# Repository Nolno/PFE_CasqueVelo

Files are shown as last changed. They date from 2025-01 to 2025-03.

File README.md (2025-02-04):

# PFE_CasqueVelo

Super projet où font qu'on arrive à faire un casque de vélo connecté qui permet de détecter la perte d'attention d'enfants atteint du syndrome de Smith Magenis.  

On les prévient ensuite avec une alerte sonore ou visuelle.

# Membres
Sahah 🌞  

Camille 😎  

Antoine 🗿  

Nolan 🫠

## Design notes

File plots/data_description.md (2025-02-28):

# Acquisitions avec le MPU6050
Le MPU6050 est la centrale inertielle que nous avons utilisée en premier, c'était celle présente sur le prototype.
Elle est composée d'un accéléromètre et d'un gyroscope, qui permettent de mesurer l'accélération et la vitesse angulaire du capteur.

### Plot 1
Le premier plot représente les angles d'Euler en fonction du temps sur 300 secondes, récupérés sur la carte master. On observe la dérive du yaw (lacet) au cours du temps, qui est due à l'accumulation d'erreurs du gyroscope. 

La calibration du gyroscope se faisait sur 10 boucles.

### Plot 2
Le deuxième plot présente la même chose mais avec une calibration plus longue (100 boucles). On n'observe que peu d'impact sur la dérive du yaw.

### Plot 3
Le troisième plot représente la même chose sur le slave, avec une calibration de 100 boucles. La dérive est légèrement 
plus faible, ce qui s'explique probablement par le fait que les deux capteurs ne sont pas exactement les mêmes.

### Plot 4
Le troisième plot représente la même chose sur le master, avec une calibration de 100 boucles, pendant 1h30. La dérive continue de s'accumuler pour atteindre 20° en 1h30.

# Acquisitions avec le IMU ICM20948
Le ICM20948 est la centrale inertielle que nous avons utilisée en deuxième, c'est celle que nous avons choisi pour remplacer le MPU6050.
Elle est composée d'un accéléromètre, d'un gyroscope et d'un magnétomètre, qui permettent de mesurer l'accélération, la vitesse angulaire et l'orientation du capteur.
L'intérêt du magnétomètre est de pouvoir mesurer l'orientation du capteur par rapport au champ magnétique terrestre, ce qui permet de compenser la dérive du yaw.

### Plot 5
Acquisition des angles d'Euler sur 370 secondes avec le ICM20948. Le yaw ne dérive pas, ce qui est cohérent avec l'utilisation du magnétomètre. Il est cependant plus bruité qu'avec le MPU6050.
Au bout de 300 secondes, on incline légèrement le capteur.

### Plot 6
Acquisition en conditions réelles sur le vélo. Le test n'était pas formalisé, on a juste roulé avec le capteur pour voir ce que ça donnait.

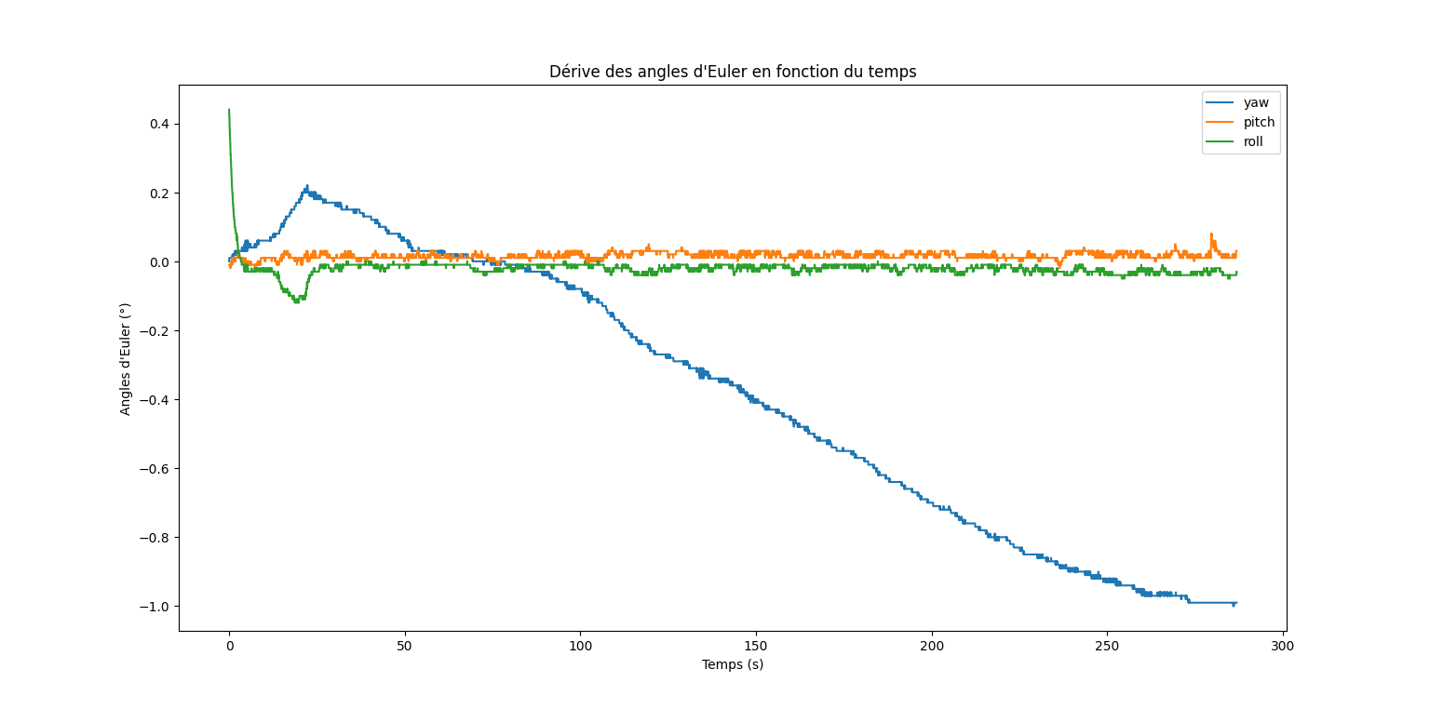
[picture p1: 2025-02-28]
plots/plot3/Figure_1.png

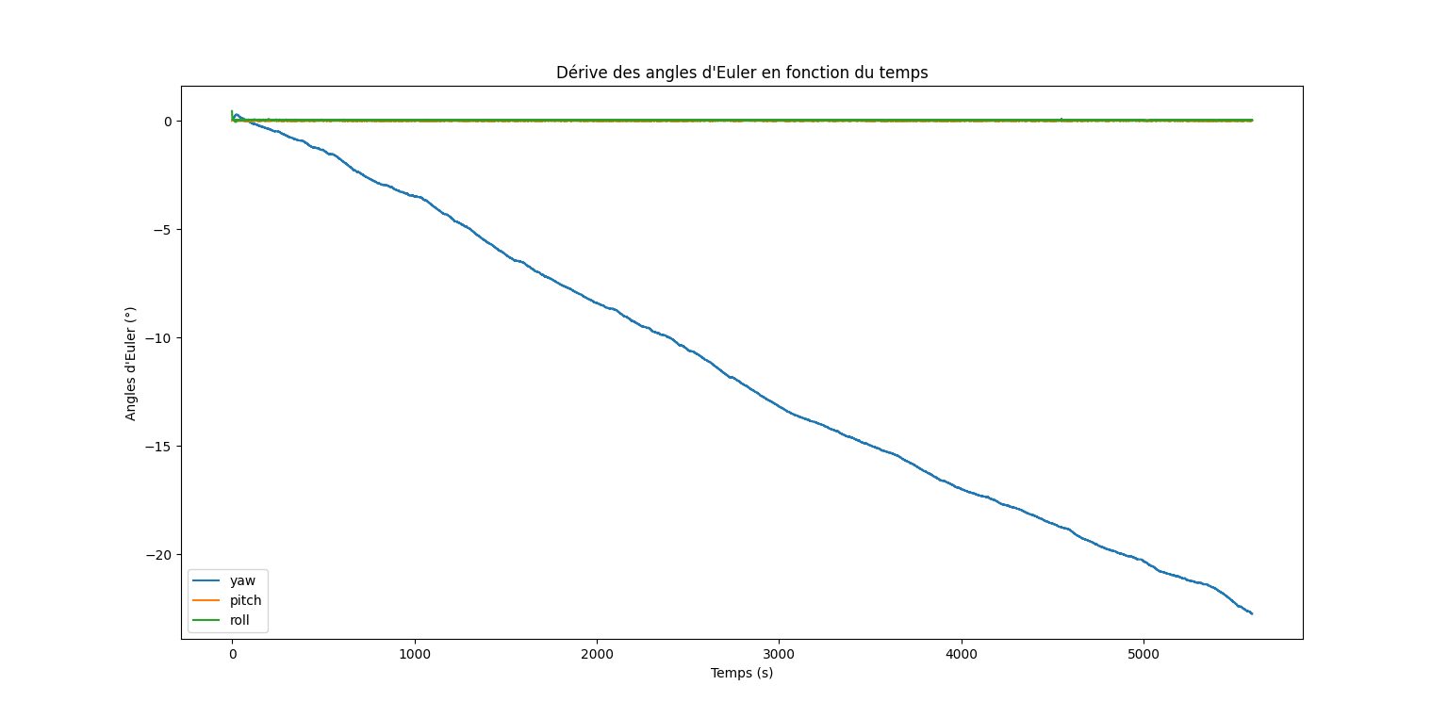
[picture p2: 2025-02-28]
plots/plot4/Figure_1.png

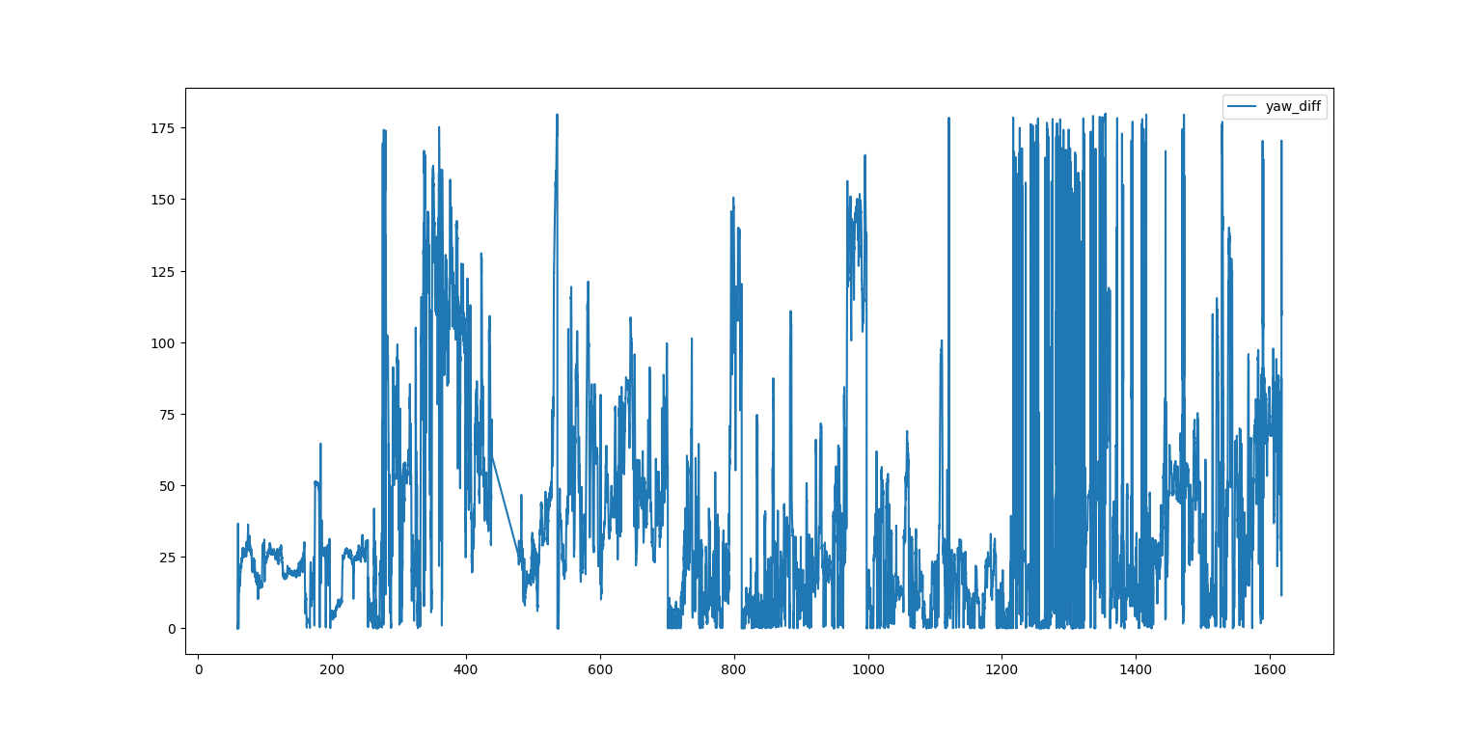
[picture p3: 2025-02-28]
plots/plot6/Figure_1.png

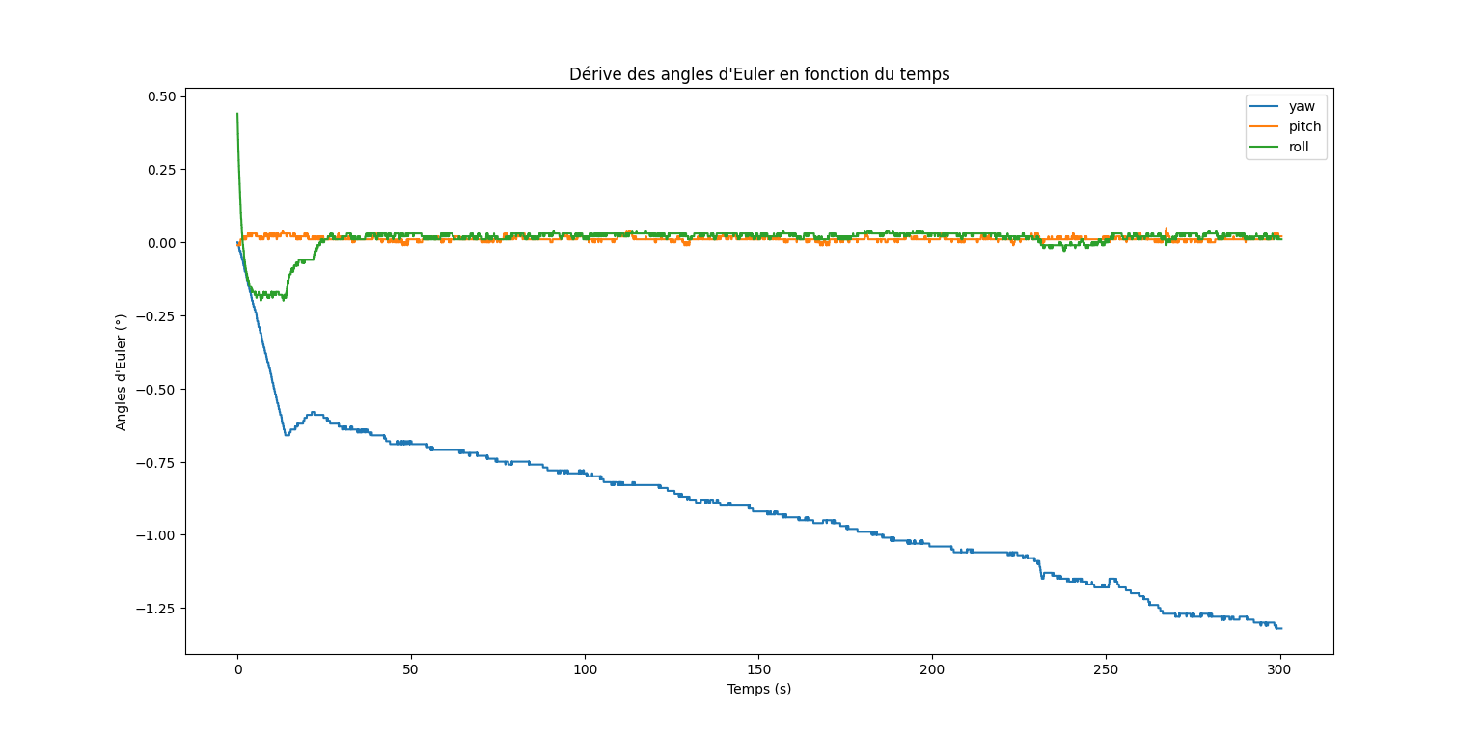
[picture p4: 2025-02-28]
plots/plot1/Figure_1.png

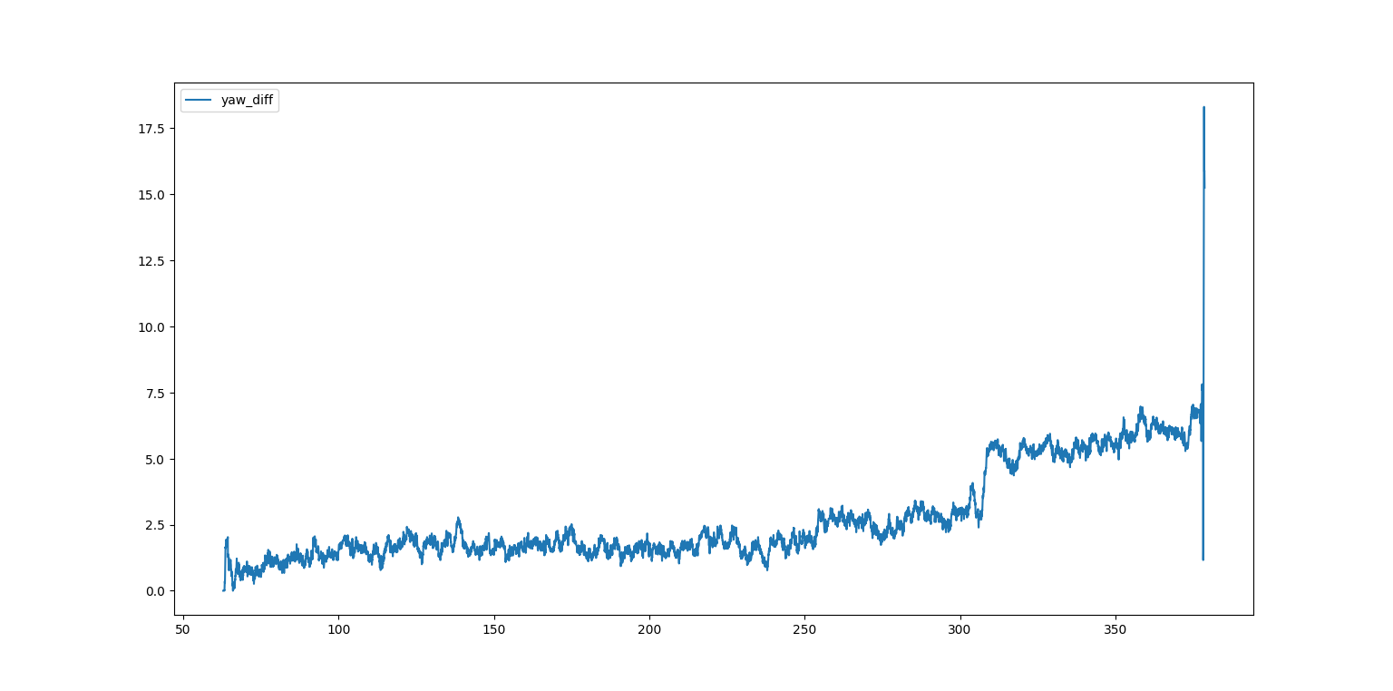
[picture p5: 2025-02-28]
plots/plot5/Figure_1.png

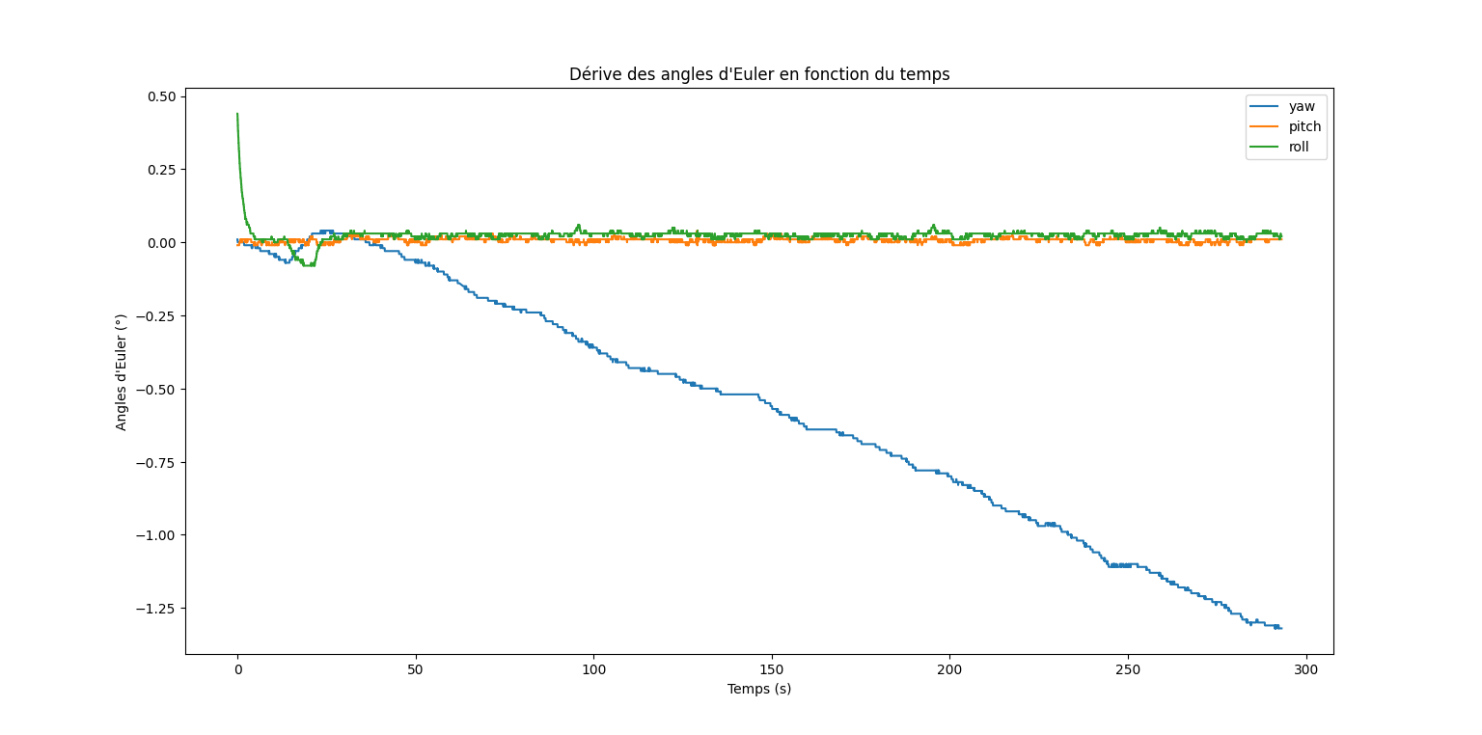
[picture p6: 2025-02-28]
plots/Plot2/Figure_1.png

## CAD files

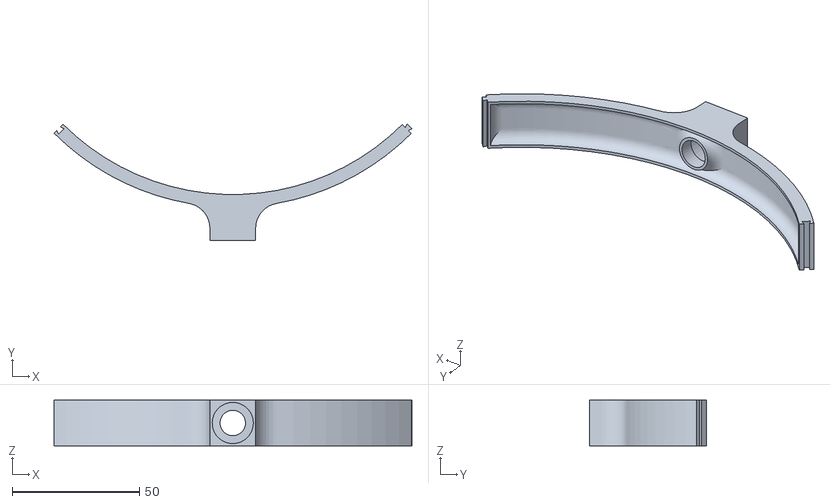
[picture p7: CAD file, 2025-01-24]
3D/banc_test/ring_2_foot.stl
140.9 x 45.9 x 18.0

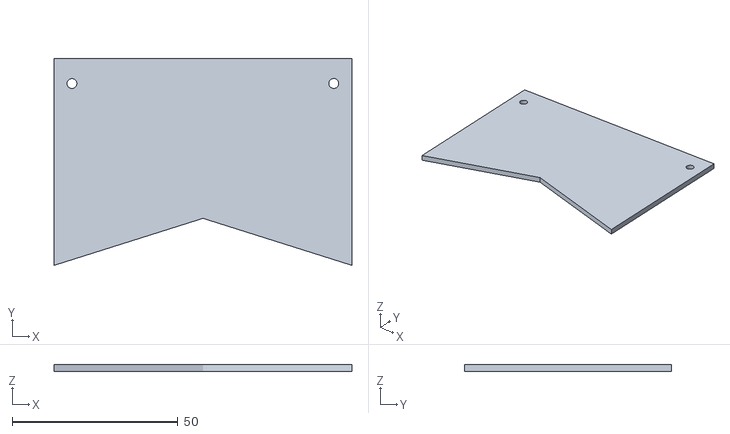
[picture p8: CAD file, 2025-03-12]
3D/casque/casque_2.stl
90.0 x 62.5 x 2.00

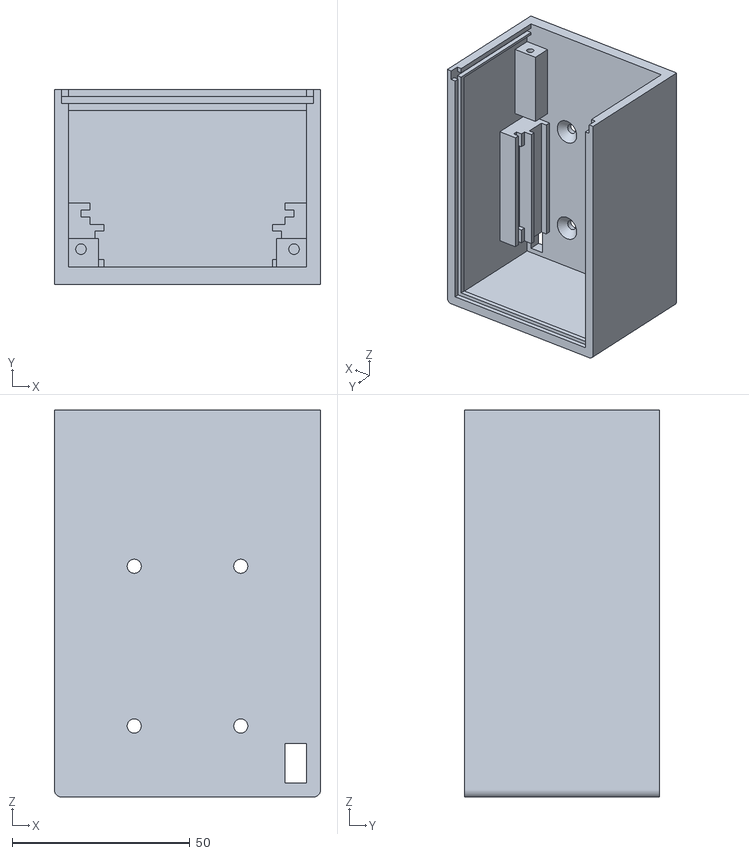
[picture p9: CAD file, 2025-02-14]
3D/Piece_Guidon/Corps1.stl
75.0 x 55.0 x 109.0

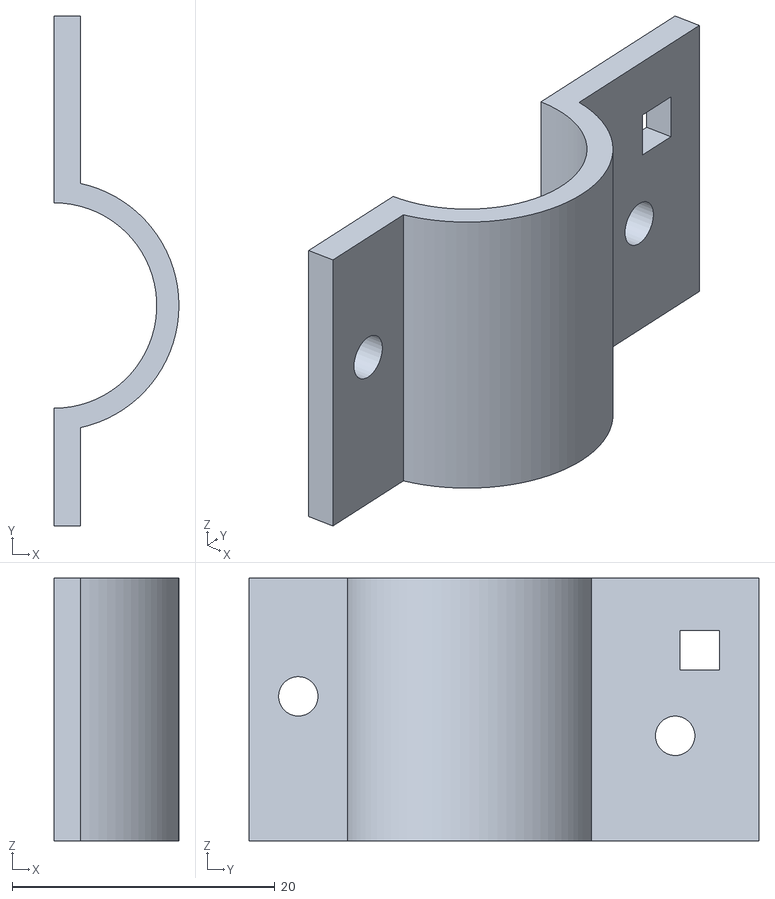
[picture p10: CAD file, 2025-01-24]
3D/supports_velo/support_fourche_2.stl
9.50 x 38.7 x 20.0

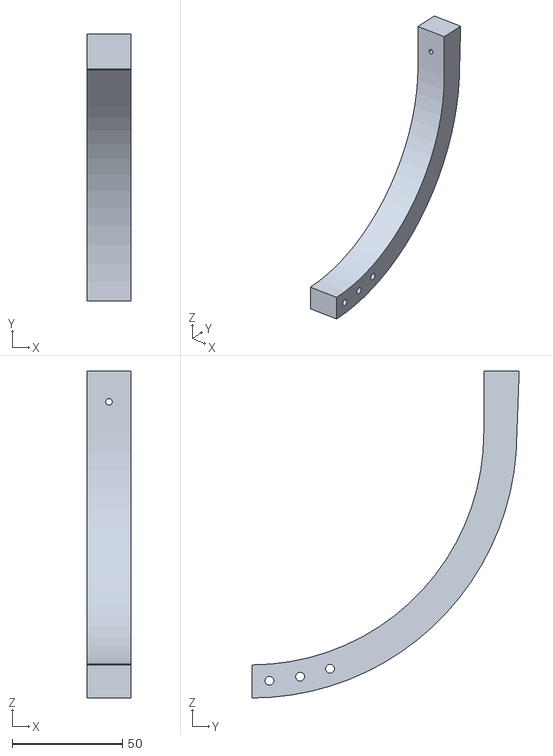
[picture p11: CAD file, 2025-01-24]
3D/banc_test/vertical_support_part_top.stl
20.0 x 121.0 x 148.0

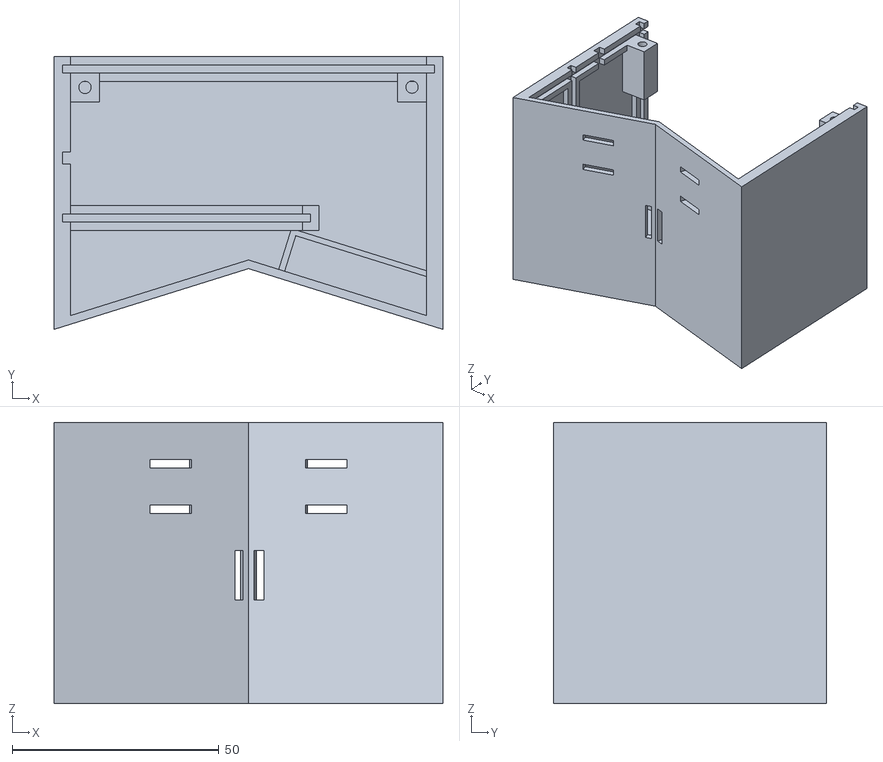
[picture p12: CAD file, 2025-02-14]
3D/casque/casque_1.stl
94.0 x 65.9 x 68.0

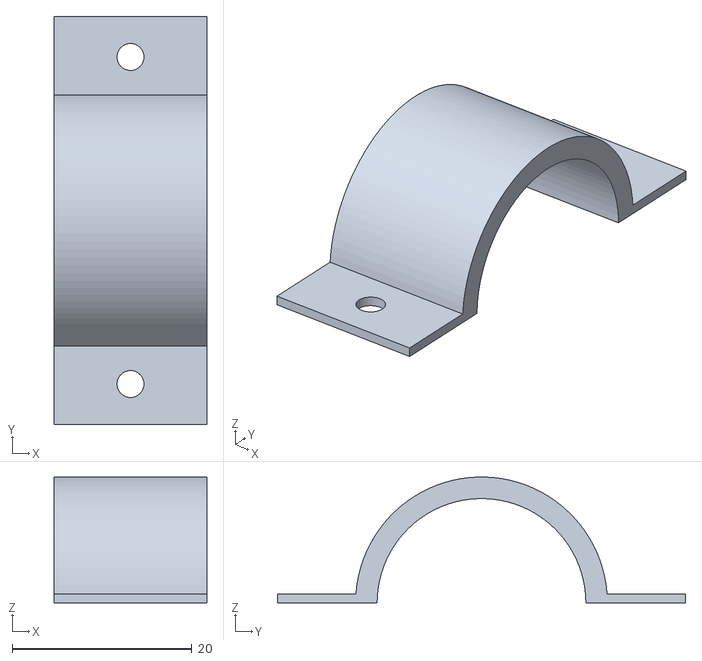
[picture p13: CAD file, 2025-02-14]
3D/Piece_Guidon/Corps3.stl
17.0 x 45.3 x 14.0

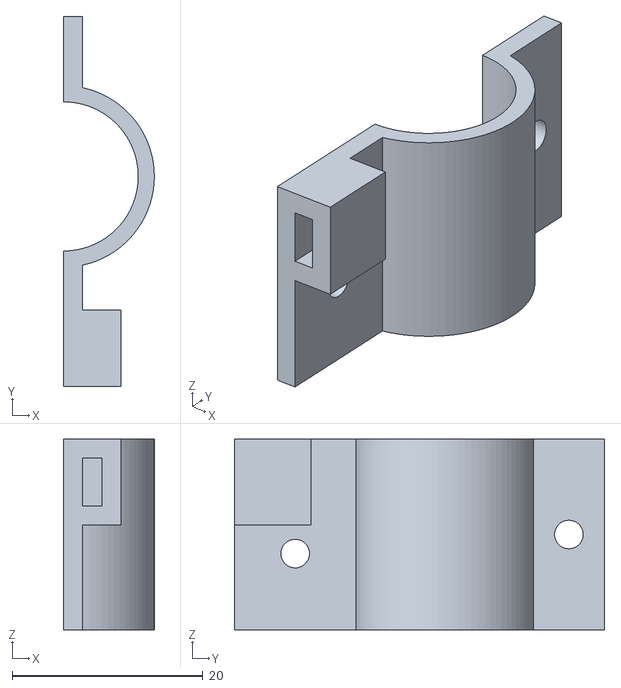
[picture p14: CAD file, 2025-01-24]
3D/supports_velo/support_fourche_1.stl
9.50 x 38.7 x 20.0

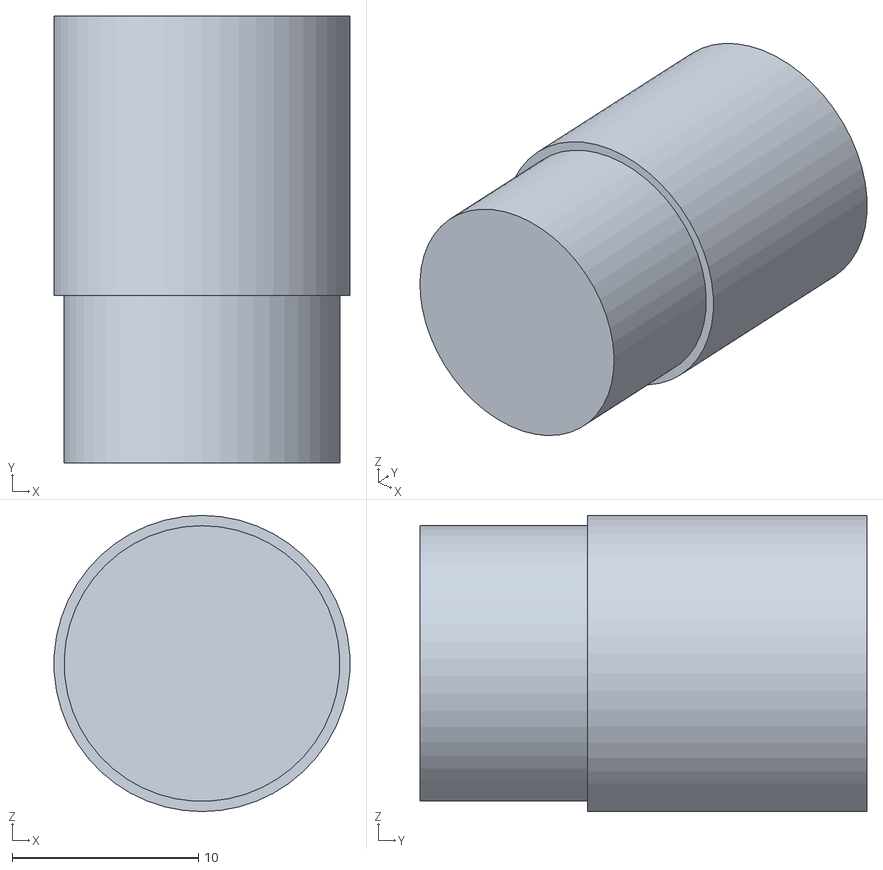
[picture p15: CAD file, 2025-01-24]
3D/banc_test/pin.stl
15.9 x 24.0 x 15.9

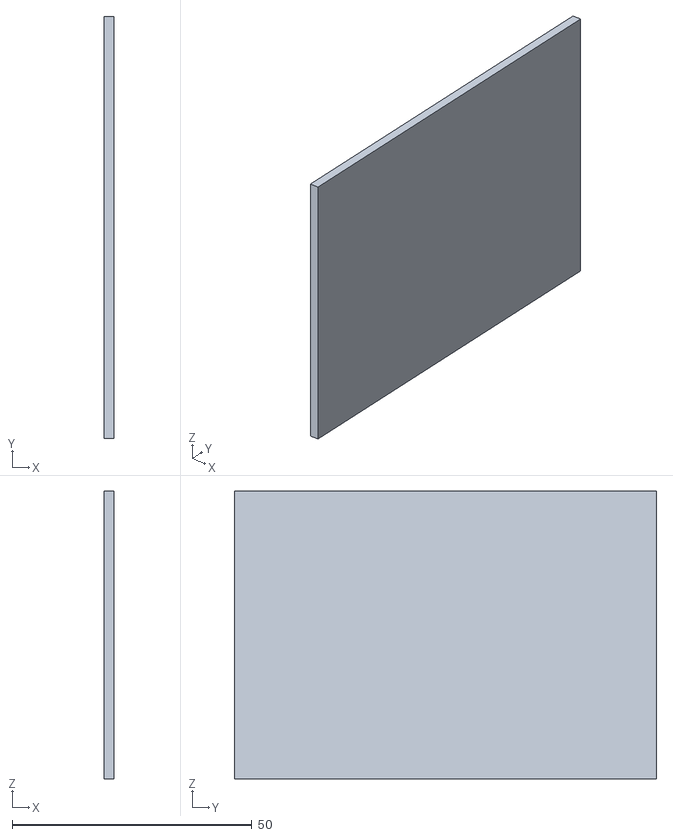
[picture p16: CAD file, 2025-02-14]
3D/casque/casque_3.stl
2.00 x 88.0 x 60.0

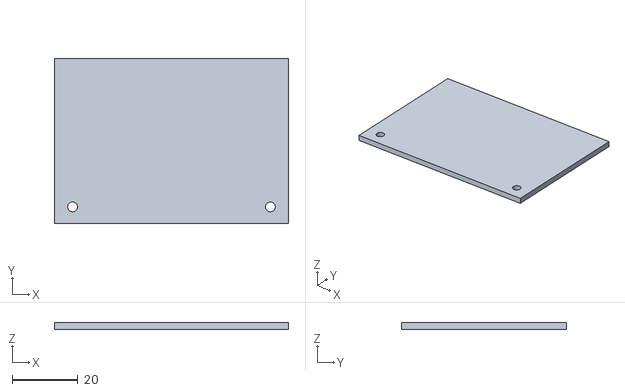
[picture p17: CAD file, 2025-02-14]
3D/Piece_Guidon/Corps2.stl
71.0 x 50.0 x 2.00

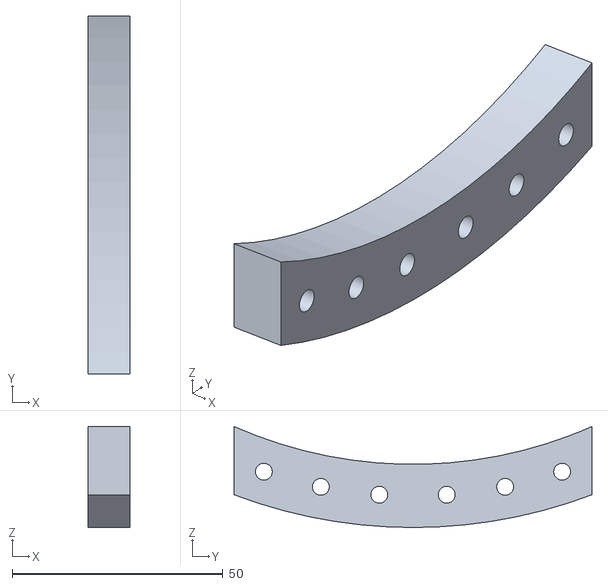
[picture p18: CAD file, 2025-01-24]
3D/banc_test/clamp_X2.stl
10.0 x 85.0 x 24.0

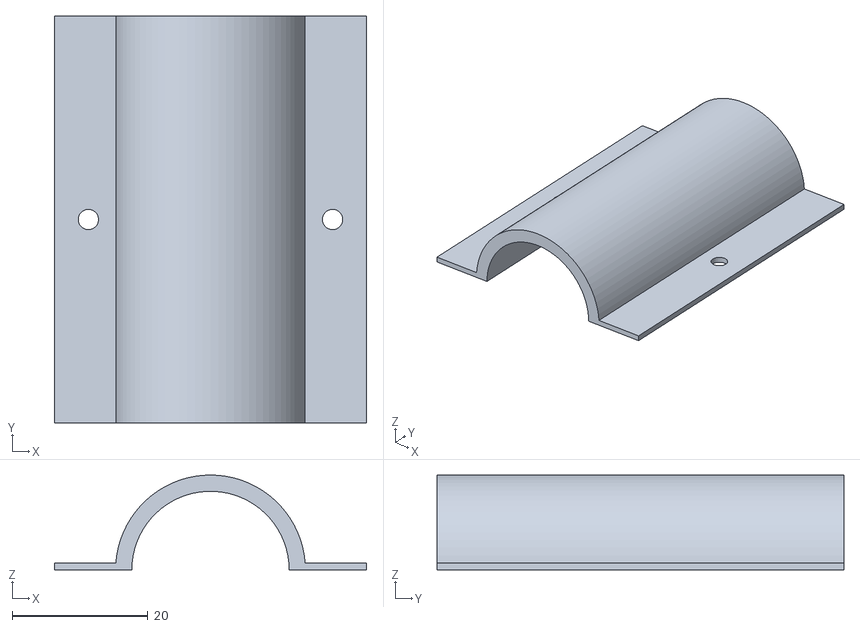
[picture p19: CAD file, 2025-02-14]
3D/Piece_Guidon/Corps5.stl
46.0 x 60.0 x 14.0

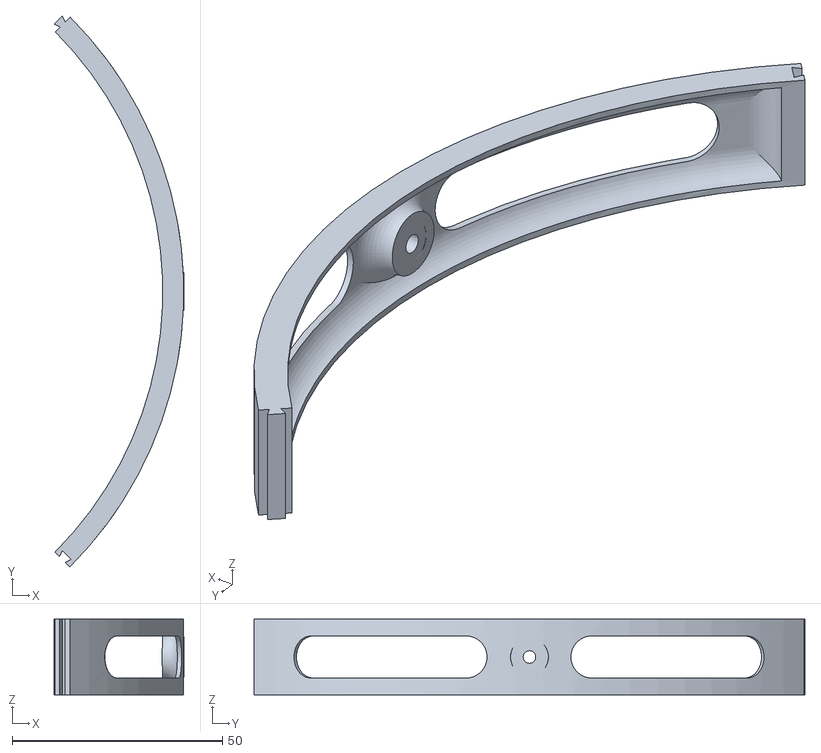
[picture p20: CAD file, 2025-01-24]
3D/banc_test/ring_1_quater_X4.stl
30.8 x 131.0 x 18.0

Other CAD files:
3D/Piece_Guidon/Corps4.stl
3D/banc_test/support_carte.stl
3D/Piece_Guidon/Piece Vélo entier.stl
3D/banc_test/Corps de maillage1.stl
3D/Piece_Guidon/case master entier.f3z
3D/banc_test/ring_2_quater_X3.stl
3D/banc_test/vertical_support_part_bottom.stl
3D/casque/boitier casque entier.f3d

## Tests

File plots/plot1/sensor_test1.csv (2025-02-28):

time | yaw | pitch | roll
7 | 0.00 | -0.01 | 0.44
18 | 0.00 | -0.01 | 0.43
28 | 0.00 | -0.01 | 0.43
37 | 0.00 | -0.01 | 0.43
48 | 0.00 | -0.01 | 0.42
58 | 0.00 | -0.01 | 0.42
67 | 0.00 | -0.01 | 0.41
77 | 0.00 | -0.01 | 0.41
88 | 0.00 | -0.01 | 0.40
98 | 0.00 | -0.01 | 0.40
107 | 0.00 | -0.01 | 0.39
118 | 0.00 | -0.01 | 0.38
128 | 0.00 | -0.01 | 0.38
137 | 0.00 | -0.01 | 0.38
148 | -0.01 | -0.01 | 0.37
158 | -0.01 | -0.01 | 0.37
167 | -0.01 | -0.01 | 0.36
178 | -0.01 | -0.01 | 0.36
188 | -0.01 | -0.01 | 0.36
198 | -0.01 | -0.01 | 0.35
208 | -0.01 | -0.01 | 0.35
218 | -0.01 | -0.01 | 0.34
228 | -0.01 | -0.01 | 0.34
238 | -0.01 | -0.01 | 0.34
248 | -0.01 | -0.01 | 0.33
258 | -0.01 | -0.01 | 0.33
268 | -0.01 | -0.01 | 0.32
278 | -0.01 | -0.01 | 0.31
288 | -0.01 | -0.01 | 0.31
298 | -0.01 | -0.01 | 0.31
308 | -0.01 | -0.01 | 0.31
318 | -0.01 | -0.01 | 0.30
328 | -0.01 | -0.01 | 0.30
338 | -0.01 | -0.01 | 0.29
348 | -0.01 | -0.01 | 0.29
358 | -0.01 | -0.01 | 0.29
368 | -0.01 | -0.01 | 0.28
378 | -0.01 | -0.01 | 0.28
388 | -0.01 | -0.01 | 0.27
398 | -0.01 | -0.01 | 0.27
408 | -0.01 | -0.01 | 0.27
418 | -0.01 | -0.01 | 0.27
428 | -0.02 | -0.01 | 0.26
438 | -0.02 | -0.01 | 0.26
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

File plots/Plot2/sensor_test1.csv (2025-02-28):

time | yaw | pitch | roll
9 | 0.01 | -0.01 | 0.44
19 | 0.01 | -0.01 | 0.44
29 | 0.01 | -0.01 | 0.43
39 | 0.01 | -0.01 | 0.43
49 | 0.01 | -0.01 | 0.43
59 | 0.01 | -0.01 | 0.43
69 | 0.00 | -0.01 | 0.42
79 | 0.00 | -0.01 | 0.42
89 | 0.00 | -0.01 | 0.41
99 | 0.00 | -0.01 | 0.41
109 | 0.00 | -0.01 | 0.41
119 | 0.00 | -0.01 | 0.40
130 | 0.00 | -0.01 | 0.40
139 | 0.00 | -0.01 | 0.39
149 | 0.00 | -0.01 | 0.39
159 | 0.00 | -0.01 | 0.39
169 | 0.00 | -0.01 | 0.38
179 | 0.00 | -0.01 | 0.38
189 | 0.00 | -0.01 | 0.38
199 | 0.00 | -0.01 | 0.38
209 | 0.00 | -0.01 | 0.37
219 | 0.00 | -0.01 | 0.37
230 | 0.00 | -0.01 | 0.36
239 | 0.00 | -0.01 | 0.36
249 | 0.00 | -0.01 | 0.36
260 | 0.00 | -0.01 | 0.36
270 | 0.00 | -0.01 | 0.36
279 | 0.00 | -0.01 | 0.36
289 | 0.00 | -0.01 | 0.35
300 | 0.00 | -0.01 | 0.35
309 | 0.00 | -0.01 | 0.34
319 | 0.00 | -0.01 | 0.34
330 | 0.00 | -0.01 | 0.34
340 | 0.00 | -0.01 | 0.34
349 | 0.00 | -0.01 | 0.34
360 | 0.00 | -0.01 | 0.33
370 | 0.00 | -0.01 | 0.33
379 | 0.00 | -0.01 | 0.33
390 | 0.00 | -0.01 | 0.32
400 | 0.00 | -0.01 | 0.32
409 | 0.00 | -0.01 | 0.32
420 | 0.00 | -0.01 | 0.31
430 | 0.00 | -0.01 | 0.31
440 | 0.00 | -0.01 | 0.31
450 | 0.00 | -0.01 | 0.31
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

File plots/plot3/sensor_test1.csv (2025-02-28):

time | yaw | pitch | roll
11 | 0.00 | -0.01 | 0.44
20 | 0.00 | -0.01 | 0.43
31 | 0.00 | -0.01 | 0.43
41 | 0.00 | -0.01 | 0.43
50 | 0.01 | -0.01 | 0.43
61 | 0.01 | -0.01 | 0.42
71 | 0.01 | -0.01 | 0.42
80 | 0.01 | -0.01 | 0.42
90 | 0.01 | -0.01 | 0.41
101 | 0.01 | -0.01 | 0.41
111 | 0.01 | -0.01 | 0.41
120 | 0.01 | -0.01 | 0.41
131 | 0.01 | -0.01 | 0.40
141 | 0.01 | -0.01 | 0.40
150 | 0.01 | -0.01 | 0.39
160 | 0.01 | -0.01 | 0.39
171 | 0.01 | -0.01 | 0.38
180 | 0.01 | -0.01 | 0.38
190 | 0.01 | -0.01 | 0.38
201 | 0.01 | -0.01 | 0.38
211 | 0.01 | -0.01 | 0.37
220 | 0.01 | -0.01 | 0.37
230 | 0.01 | -0.01 | 0.37
241 | 0.01 | -0.01 | 0.36
250 | 0.01 | -0.01 | 0.36
260 | 0.01 | -0.01 | 0.36
271 | 0.01 | -0.01 | 0.36
281 | 0.01 | -0.01 | 0.36
290 | 0.01 | -0.01 | 0.36
300 | 0.01 | -0.01 | 0.35
311 | 0.01 | -0.01 | 0.35
320 | 0.01 | -0.01 | 0.34
330 | 0.01 | -0.02 | 0.34
341 | 0.01 | -0.02 | 0.34
350 | 0.01 | -0.02 | 0.34
360 | 0.01 | -0.02 | 0.34
370 | 0.01 | -0.02 | 0.33
381 | 0.01 | -0.02 | 0.33
390 | 0.01 | -0.01 | 0.32
400 | 0.01 | -0.01 | 0.32
411 | 0.01 | -0.01 | 0.31
420 | 0.01 | -0.01 | 0.31
430 | 0.01 | -0.01 | 0.31
440 | 0.01 | -0.01 | 0.31
451 | 0.01 | -0.01 | 0.31
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

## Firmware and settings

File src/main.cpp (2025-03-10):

/**
   * @file main.cpp
   * @author Antoine Martin
   * @brief  Code principal du projet, permettant de récupérer les données des capteurs et de les envoyer via Bluetooth.
   * Inclut également la gestion de l'alarme et de l'enregistrement des données sur la carte SD. Le code doit être
   * exécuté sur un ESP32-WROOM-32E.
   * @version 1.0
   * @date 25/02/2025
   *
   * @copyright Copyright (c) 2025
   *
   */


#include <Alarm.h>
#include <Arduino.h>
#include <SD.h>
#include <Wire.h>
#include "BluetoothSerial.h"
#include "MPU.h"
#include "Tachymeter.h"
#include "pitches.h"


/******************************************************************************
 *                                   DEFINES                                  *
 ******************************************************************************/

// Baudrate pour la communication série. Doit être le même que celui configuré dans le platformio.ini
#define BAUDRATE 115200

//############################ CAPTEUR A EFFET HAL ###################################

// Fréquence minimale pour laquelle le capteur à effet Hall est capable de détecter les impulsions
#define MIN_FREQUENCY 0.1
// Facteur de conversion secondes/microsecondes
#define MICRO_CONSTANT 1.0E-6
// Rayon de la roue en mètres : À MODIFIER EN FONCTION DE LA ROUE UTILISÉE
#define WHEEL_RADIUS 0.31

//############################ BLUETOOTH ###################################
#if !defined(CONFIG_BT_SPP_ENABLED)
  #error Serial Bluetooth not available or not enabled. It is only available for the ESP32 chip.
#endif

//############################ PINS ###################################

#define CS_PIN 5 /**< CS pin de la carte SD */
#define PIN_BUZZER 2 // Pin du buzzer
#define PIN_HAL 25  // Pin du capteur à effet Hall
#define PIN_LED 33 // Pin de la LED
#define INTERRUPT_PIN 15 // Pin de l'interruption du MPU - Non utilisé dans ce code


/******************************************************************************
 *                         Prototypes des fonctions locales                   *
 ******************************************************************************/

//############################ BLUETOOTH ###################################
/**
 *  @brief Fonction pour connecter le MASTER au SLAVE via Bluetooth
 */
void connectSlave();

/**
 * @brief
 *  Fonction de callback pour le statut du Bluetooth
 * @param event Événement du Bluetooth
 * @param param Paramètre du callback
 */
void getBluetoothStatus(esp_spp_cb_event_t event, esp_spp_cb_param_t* param);

/**
 * @brief
 *  Récupère les valeurs de l'accélération et de l'orientation du MPU de slave via Bluetooth
 * @param ypr_slave
 *  Tableau contenant les angles de l'orientation de slave [yaw, pitch, roll] [lacet, tangage, roulis] en radians
 */
void getSlaveData(float (&ypr_slave)[3]);
//############################ SON ###################################
/**
 * @brief
 *  Son à jouer pour indiquer la connexion au slave (dernière étape de l'initialisation).
 */
void playBtConnexionSuccessSound();

/**
 * @brief
 *  Son à jouer pour indiquer la fin de la calibration.
 */
void playCalibrationSound();
//############################ SD CARD ###################################
/**
 * @brief
 *  Fonction pour enregistrer les données sur la carte SD, et les afficher dans le moniteur série
 * @param ypr_master
 *  Tableau contenant les angles de l'orientation de master [yaw, pitch, roll] [lacet, tangage, roulis] en degrés
 * @param ypr_slave
 *  Tableau contenant les angles de l'orientation de slave [yaw, pitch, roll] [lacet, tangage, roulis] en degrés
 * @param ypr_diff
 *  Tableau contenant les différences entre les angles de l'orientation de master et de slave [yaw, pitch, roll] [lacet, tangage, roulis] en degrés
 * @param speed
 *  Vitesse du vélo en km/h
 * @param alarmState
 *  État de l'alarme (true = alarme activée, false = alarme désactivée)
 */
void logData(const float (&ypr_master)[3], const float (&ypr_slave)[3], const float (&ypr_diff)[3], double speed,
             boolean alarmState);

/******************************************************************************
 *                             VARIABLES GLOBALES                             *
 ******************************************************************************/
//############################ ALARME ###################################

// Objet pour la gestion de l'alarme
Alarm alarmSystem(PIN_BUZZER, PIN_LED, 70, 3, 0.1, 0.1);
//############################ MPU ###################################

// Objet pour la gestion du MPU
MPU mpu;
float ypr[3]; // Tableau contenant les angles de l'orientation [yaw, pitch, roll] du master en degrés
float yprSlave[3]; // Tableau contenant les angles de l'orientation [yaw, pitch, roll] du slave en degrés
// ############################ TACHYMÈTRE ###################################

// Objet pour la gestion du tachymètre
Tachymeter tachymeter(PIN_HAL, PIN_BUZZER, WHEEL_RADIUS, 0.55);
//############################ BLUETOOTH ###################################

// Variables pour la gestion de la connexion Bluetooth
unsigned long previousMillisReconnect;
/**< Variable pour stocker le temps écoulé depuis la dernière tentative de reconnexion */
bool SlaveConnected; /**< Variable pour stocker l'état de la connexion Bluetooth */
int recatt = 0; /**< Variable utilisée pour stocker le nombre d'essais de reconnexion */

String myName = "ESP32-BT-Master";
/**< Variable contenant le nom du périphérique Bluetooth MASTER; juste pour l'impression */
String slaveName = "ESP32-BT-Slave";
/**< Variable contenant le nom du périphérique Bluetooth SLAVE; juste pour l'impression */
String macAdd = "64:B7:08:29:35:72";
/**< Variable contenant l'adresse MAC du périphérique Bluetooth SLAVE; juste pour l'impression */
uint8_t slaveAddress[6] = {0x64, 0xB7, 0x08, 0x29, 0x35, 0x72};
/**< Variable contenant l'adresse MAC du périphérique Bluetooth SLAVE, utilisée pour la connexion */

BluetoothSerial SerialBT; /**< Objet pour la communication série Bluetooth */

// Variables pour la réception des données Bluetooth
char receivedBuffer[1550]; /**< Buffer pour stocker les données reçues via Bluetooth */
int bufferIndex = 0; /**< Index pour parcourir le buffer */
char receivedChar2; /**< Caractère reçu via Bluetooth */
char* token; /**< tokens extraits du buffer */
constexpr char t[2] = ","; /**< Délimiteur pour la fonction strtok */

//############################ CARTE SD ###################################
File myFile; /**< Objet pour la gestion de la carte SD */

// ############################ BOUTON ###################################
constexpr int buttonPin = 32; /**< Broche du bouton */
int buttonState = 0; /**< État du bouton */

// Variables pour stocker les angles initiaux
float initialMasterYaw = 0; /**< Yaw initial du master — utilisé pour la mise à zéro */
float initialSlaveYaw = 0; /**< Yaw initial du slave — utilisé pour la mise à zéro */

// Variable pour stocker l'état du système
bool systemStarted = false; /**< État du système (true = système démarré, false = système arrêté) */


/******************************************************************************
 *                              SETUP AND LOOP                                *
 ******************************************************************************/

/**
 * @brief
 *  Fonction de configuration du programme. Cette fonction est exécutée une seule fois au démarrage du programme.
 */
void setup()
{
    Serial.begin(115200); //  Initialisation de la communication série
    Wire.begin(); //  Initialisation de la communication I2C
    //############################ SETUP DU BOUTON ###################################
    pinMode(buttonPin, INPUT_PULLUP); //  Initialisation de la broche du bouton, avec une résistance de tirage pour que le bouton soit HIGH par défaut
    //############################ SETUP DE LA LED ###################################
    pinMode(PIN_LED, OUTPUT); //  Initialisation de la broche de la LED
    //############################ INITIALISATION DE L'ALARME ###################################
    alarmSystem.init(); //  Initialisation de l'alarme
    //############################ INITIALISATION DU TACHYMÈTRE ###################################
    Tachymeter::instance = &tachymeter;
    tachymeter.initialize(); //  Initialisation du tachymètre
    //############################ INITIALISATION DU MPU ###################################
    mpu.initialize(); //  Initialisation du MPU - Inclut la calibration
    playCalibrationSound();  //  Jouer le son de fin de calibration
    //############################ SD CARD Setup ###################################
    pinMode(CS_PIN, OUTPUT);  //  Initialisation de la broche CS - permet de sélectionner la carte SD

    Serial.print("Initializing SD card... ");
    if (!SD.begin(CS_PIN))
    {
        Serial.println("Card initialization failed!");
        // ReSharper disable once CppDFAEndlessLoop - Ignore le warning de boucle infinie
        while (true); //  Si la carte SD n'est pas détectée, on arrête le programme
    }
    Serial.println("Initialization done.");

    Serial.println("Creating example.csv...");
    myFile = SD.open("/example.csv", FILE_WRITE); //  Créer un fichier CSV pour stocker les données
    // Écrire les en-têtes dans le fichier
    myFile.println(
        "time,yaw_master,pitch_master,roll_master,yaw_slave,pitch_slave,roll_slave,yaw_diff,pitch_diff,roll_diff,speed,alarmState,limit_angle,limit_time");
    myFile.close();  //  Fermer le fichier

    //############################ BLUETOOTH Setup ################################
    SlaveConnected = false; //  Flag pour indiquer si le slave est connecté : initialisé à false (non connecté)

    SerialBT.register_callback(getBluetoothStatus); // Enregistrer la fonction de callback pour le statut du Bluetooth
    SerialBT.begin(myName, true); //   Initialisation du Bluetooth en mode MASTER
    Serial.printf("The device \"%s\" started in master mode, make sure slave BT device is on!\n", myName.c_str());
    connectSlave(); // Connexion au slave
}

/**
 * @brief
 *  Fonction principale du programme. Cette fonction est exécutée en boucle après la fonction setup().
 */
void loop()
{
    mpu.update(); // Routine du MPU
    tachymeter.update(); // Routine du tachymètre


    // Bluetooth - MPU routine
    if (!SlaveConnected) // Si le slave n'est pas connecté on tente de se reconnecter
    {
        if (millis() - previousMillisReconnect >= 10000)
        {
            previousMillisReconnect = millis();
            recatt++;
            Serial.print("Trying to reconnect. Attempt No.: ");
            Serial.println(recatt);
            Serial.println("Stopping Bluetooth...");
            SerialBT.end();
            Serial.println("Bluetooth stopped !");
            Serial.println("Starting Bluetooth...");
            SerialBT.begin(myName, true);
            Serial.printf("The device \"%s\" started in master mode, make sure slave BT device is on!\n",
                          myName.c_str());
            connectSlave();
            Serial.println(
                "time,yaw_master,pitch_master,roll_master,yaw_slave,pitch_slave,roll_slave,yaw_diff,pitch_diff,roll_diff,speed");
        }
    }
    if (SerialBT.available()) // Si des données sont disponibles sur le port série Bluetooth
    {
        // On lit les données des capteurs
        mpu.getAveragedYPR(ypr); // Récupérer les angles de l'orientation du master
        getSlaveData(yprSlave); // Récupérer les angles de l'orientation du slave
        double speedKmh = tachymeter.getSpeed() * 3.6; // Récupérer la vitesse en km/h
        // speedKmh = 15; // Vitesse simulée pour les tests, on remplace la vitesse réelle par x km/h

        // Lit l'état du bouton - Le système démarre lorsque le bouton est pressé, les angles sont mis à zéro
        buttonState = digitalRead(buttonPin);
        if (buttonState == LOW)
        { // Le bouton est pressé
            Serial.println("Mise à zéro");
            // Initialiser les angles de départ
            initialMasterYaw = ypr[0];
            initialSlaveYaw = yprSlave[0];
            // Démarrer le système
            systemStarted = true;
        }
        // Routine principale : si le système est démarré (le bouton a été pressé au moins une fois)
        if (systemStarted)
        {
            // Récupérer les angles de l'orientation du master
            ypr[0] = ypr[0] - initialMasterYaw;
            if (ypr[0] < 0) // Correction pour avoir un angle entre [0, 360°] au lieu de [-180, 180°]
            {
                ypr[0] = 360 + ypr[0];
            }
            // Même chose pour le slave
            yprSlave[0] = yprSlave[0] - initialSlaveYaw;
            if (yprSlave[0] < 0)
            {
                yprSlave[0] = 360 + yprSlave[0];
            }
            // REMARQUE : Les angles de tangage et de roulis ne sont pas modifiés. Il sera nécessaire de le faire si
            // on souhaite les utiliser.

            // Calculer les différences entre les angles de l'orientation du master et du slave.
            // La formule suivante permet de calculer la différence entre deux angles en tenant compte de la périodicité
            // de 360°. Par exemple, la différence entre 10° et 350° est de 20° et non de 340°.
            float ypr_diff[3] = {
                180 - abs(abs(ypr[0] - yprSlave[0]) - 180),
                180 - abs(abs(ypr[1] - yprSlave[1]) - 180),
                180 - abs(abs(ypr[2] - yprSlave[2]) - 180)
            };

            // Mise à jour de l'alarme avec les différences d'angles et la vitesse actuelle
            boolean alarmState = alarmSystem.update(ypr_diff, speedKmh);
            // Enregistrement des données dans le fichier CSV de la carte SD
            logData(ypr, yprSlave, ypr_diff, speedKmh, alarmState);
        }
        else // Si le système n'est pas démarré, on affiche les angles bruts (a des fins de débogage uniquement)
        {
            Serial.print("Système non démarré --> Yaw : ");
            Serial.print(ypr[0]);
            Serial.print(" Roll : ");
            Serial.print(ypr[1]);
            Serial.print(" Pitch : ");
            Serial.println(ypr[2]);
            // REMARQUE : Tant que le système n'est pas démarré, les données ne sont pas enregistrées sur la carte SD.
        }
    }
}


void getSlaveData(float (&ypr_slave)[3])
{
    bufferIndex = 0; // Réinitialiser l'index avant lecture
    memset(receivedBuffer, 0, sizeof(receivedBuffer)); // Effacer le buffer

    // Lecture des données reçues via Bluetooth
    while (SerialBT.available())
    {
        receivedChar2 = SerialBT.read(); // Lire le caractère
        if (receivedChar2 == '!') // Fin de la transmission
        {
            receivedBuffer[bufferIndex] = '\0'; // Terminer la chaîne
            break;
        }
        // On n'a pas reçu le caractère de fin, on stocke donc le caractère dans le buffer
        if (bufferIndex < sizeof(receivedBuffer) - 1) // Vérifier les limites du tableau
        {
            receivedBuffer[bufferIndex] = receivedChar2; // Stocker le caractère
            bufferIndex++; // Incrémenter l'index
        }
        else
        {
            Serial.println("Buffer overflow detected!"); // Détection de dépassement
            break;
        }
    }
    // Extraire les données du buffer. Les données sont séparées par des virgules (délimiteur défini par t, voir plus haut)
    token = strtok(receivedBuffer, t);
    if (token != nullptr) // Si le token n'est pas null (données reçues)
    {
        ypr_slave[0] = atof(token); // Convertir la chaîne en float
        token = strtok(nullptr, t); // Lire le prochain token
    }
    else
    {   // Si le token est null, on initialise la valeur à 0
        ypr_slave[0] = 0;
    }
    // On répète le processus pour les deux autres valeurs
    if (token != nullptr)
    {
        ypr_slave[1] = atof(token);
        token = strtok(nullptr, t);
    }
    else
    {
        ypr_slave[1] = 0;
    }
    if (token != nullptr)
    {
        ypr_slave[2] = atof(token);
    }
    else
    {
        ypr_slave[2] = 0;
    }
    // Envoyer un caractère d'Acknowledgement au slave (On indique au slave que les données ont été reçues et traitées)
    // On est apte à recevoir de nouvelles données
    SerialBT.write('A');
}


void getBluetoothStatus(esp_spp_cb_event_t event, esp_spp_cb_param_t* param)
{
    // Gestion des événements Bluetooth
    if (event == ESP_SPP_OPEN_EVT)
    {
        Serial.println("Client Connected");
        SlaveConnected = true;
        recatt = 0;
    }
    else if (event == ESP_SPP_CLOSE_EVT)
    {
        Serial.println("Client Disconnected");
        SlaveConnected = false;
    }
}


void connectSlave()
{
    // Tant que le slave n'est pas connecté, on tente de se connecter
    while (!SerialBT.connected())
    {
        Serial.println("Function BT connection executed");
        Serial.printf("Connecting to slave BT device named \"%s\" and MAC address \"%s\" is started.\n",
                      slaveName.c_str(),
                      macAdd.c_str());
        SerialBT.connect(slaveAddress); // Connexion au slave via son adresse MAC
    }
    playBtConnexionSuccessSound(); // Jouer le son de connexion
    // On vide le buffer de réception
    while (SerialBT.available())
    {
        SerialBT.read();
    }
}


void logData(const float (&ypr_master)[3], const float (&ypr_slave)[3], const float (&ypr_diff)[3], const double speed,
             const boolean alarmState)
{
    myFile = SD.open("/example.csv", FILE_APPEND); // Ouvrir le fichier en mode ajout
    if (myFile) // Si le fichier est ouvert avec succès
    {
        // Créer une chaîne de caractères pour stocker les données au format CSV
        String dataString = "";
        dataString += String(millis()) + ",";
        dataString += String(ypr_master[0]) + "," + String(ypr_master[1]) + "," + String(ypr_master[2]) + ",";
        dataString += String(ypr_slave[0]) + "," + String(ypr_slave[1]) + "," + String(ypr_slave[2]) + ",";
        dataString += String(ypr_diff[0]) + "," + String(ypr_diff[1]) + "," + String(ypr_diff[2]) + ",";
        dataString += String(speed) + "," + String(alarmState) + ",";

        // Ajouter les limites calculées
        std::pair<double, double> limits = alarmSystem.getLimits(speed);
        dataString += String(limits.first) + "," + String(limits.second);

        // Imprimer la chaîne dans le fichier
        myFile.println(dataString);
        myFile.flush(); // Vider le buffer
        myFile.close(); // Fermer le fichier

        // Créer une chaîne de caractères pour l'affichage aligné dans le moniteur série
        char formattedString[512];
        sprintf(formattedString,
                "time: %lu YAW --> Master: %7.2f Slave: %7.2f Diff: %7.2f PITCH --> Master: %7.2f Slave: %7.2f Diff: %7.2f ROLL --> Master: %7.2f Slave: %7.2f Diff: %7.2f Speed: %7.2f limit_angle: %7.2f limit_time: %7.2f",
                millis(),
                ypr_master[0], ypr_slave[0], ypr_diff[0],
                ypr_master[1], ypr_slave[1], ypr_diff[1],
                ypr_master[2], ypr_slave[2], ypr_diff[2],
                speed,
                limits.first, limits.second);

        // Imprimer la chaîne formatée dans la console série
        Serial.println(formattedString);
    }
    else // Si le fichier n'a pas pu être ouvert
    {
        Serial.println("Error opening file.");
    }
}


void playCalibrationSound()
{
    // Définir la mélodie à jouer. Les notes sont définies dans le fichier pitches.h
    int melody[] = {NOTE_G4, NOTE_B4, NOTE_D5};
    constexpr int noteDuration = 1000 / 4; // Durée de chaque note (en ms)
    constexpr int pauseBetweenNotes = noteDuration * 1.30; // Pause entre chaque note
    for (const int thisNote : melody) // Jouer chaque note
    {
        tone(PIN_BUZZER, thisNote, noteDuration); // Jouer la note pendant la durée spécifiée
        delay(pauseBetweenNotes); // Attendre
        noTone(PIN_BUZZER); // Arrêter le son
    }
}


void playBtConnexionSuccessSound()
{
    // Mélodie de connexion réussie
    constexpr int duration = 125; // Durée de chaque note (en ms)

    tone(PIN_BUZZER, NOTE_E5, duration);
    delay(duration);
    tone(PIN_BUZZER, NOTE_CS5, duration);
    delay(duration);
    tone(PIN_BUZZER, NOTE_CS5, duration);
    delay(duration);
    delay(duration);
    // Descente
    tone(PIN_BUZZER, NOTE_B4, duration);
    delay(duration);
    tone(PIN_BUZZER, NOTE_CS5, duration);
    delay(duration);
    tone(PIN_BUZZER, NOTE_E5, duration);
    delay(duration);
    noTone(PIN_BUZZER); // Stop le son
    delay(duration);
}

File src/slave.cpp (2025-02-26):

/**
 * @file main.cpp
 * @author Antoine Martin
 * @brief Code de fonctionnement du slave. Ce code est exécuté sur un ESP32-WROOM-32E.
 * @version 1.0
 * @date 25/02/2024
 *
 * @copyright Copyright (c) 2025
 *
 */

#include <Wire.h>
#include <Arduino.h>
#include "MPU.h"
#include "BluetoothSerial.h"

//############################ PINS ###################################
#define INTERRUPT_PIN 15 /**< Pin d'interruption du MPU */

//############################ MPU ###################################
MPU mpu; /**< Objet pour la gestion du MPU */


//############################ BLUETOOTH ###################################
#if !defined(CONFIG_BT_ENABLED) || !defined(CONFIG_BLUEDROID_ENABLED)
#error Bluetooth is not enabled! Please run `make menuconfig` to and enable it
#endif

BluetoothSerial SerialBT;

String deviceName = "ESP32-BT-Slave"; /**< BT: Stockage du nom du périphérique Bluetooth SLAVE */
String MACadd = "64:B7:08:29:35:72"; /**< Adresse MAC du périphérique Bluetooth SLAVE */
uint8_t address[6]; /**< Adresse MAC du périphérique Bluetooth SLAVE */

#define MAX_BUFFER_SIZE 256 /**< Taille maximale du buffer de réception */
#define MAX_BUFFER_SIZE_6 1550 /**< Taille maximale du buffer de réception : 6*256 + espace pour 1 caractère (char) */

// Déclaration des buffers comme des arrays de char
char message[MAX_BUFFER_SIZE_6]; /**< Buffer pour stocker les données reçues via Bluetooth */
char buffer[MAX_BUFFER_SIZE_6]; /**< Buffer pour stocker et concaténer les données à envoyer via Bluetooth */

float avg_yaw = 0, avg_pitch = 0, avg_roll = 0;
/**< Variables pour stocker les valeurs moyennes des angles d'orientation */

bool ack_received = true; /**< Stocke l'état de l'accusé de réception */
int i = 0; /**< Variable pour parcourir les adresses MAC */
unsigned long last_ack = 0; /**< Temps du dernier ACK reçu */
unsigned long temps; /**< Temps actuel en millisecondes */
/**
 * @brief
 *  Fonction de configuration du programme. Cette fonction est exécutée une seule fois au démarrage du programme.
 */
void setup()
{
    Wire.begin(); // Initialisation de la communication I2C
    Serial.begin(115200); // Initialisation de la communication série
    while (!Serial) // Attendre que la communication série soit prête
        delay(10);

    //############################ MPU  Setup ###################################
    mpu.initialize(); // Initialisation du MPU - inclut le calibrage du magnétomètre

    //############################ BLUETOOTH Setup ###################################
    esp_read_mac(address, ESP_MAC_BT); // Récupérer l'adresse MAC du périphérique Bluetooth
    SerialBT.begin(deviceName); // Initialisation du Bluetooth en mode SLAVE
    while (!SerialBT.connected(1000)) // Attendre la connexion
    {
        Serial.println("Waiting for connection...");
    }
    ack_received = true; // Initialiser l'accusé de réception à true
    while (i < 6) // Afficher l'adresse MAC du périphérique Bluetooth
    {
        Serial.print(address[i], HEX);
        Serial.print("\t");
        i++;
    }
    Serial.println();
    delay(3000);
    memset(message, 0, sizeof(message)); // Initialiser le buffer de réception
    memset(buffer, 0, sizeof(buffer)); // Initialiser le buffer d'envoi
}

/**
 * @brief
 *  Fonction principale du programme. Cette fonction est exécutée en boucle après la fonction setup().
 */
void loop()
{
    mpu.update(); // Routine du MPU
    if (ack_received) // Si un ACK est reçu (le master est prêt à recevoir de nouvelles données)
    {
        mpu.getAveragedYPR(avg_yaw, avg_pitch, avg_roll); // Récupérer les angles de l'orientation moyens
        snprintf(buffer, sizeof(buffer), "%f,%f,%f!",avg_yaw, avg_pitch, avg_roll); // Stocker les valeurs dans le buffer
        SerialBT.write((uint8_t*)buffer, strlen(buffer));  // Envoyer les données via Bluetooth
        Serial.println(buffer); // Afficher les données dans le moniteur série

        ack_received = false; // Attendre le prochain ACK
        // Reset for next batch
        memset(message, 0, sizeof(message));
        memset(buffer, 0, sizeof(buffer));
    }


    // Vérifier si un ACK est reçu
    if (SerialBT.available())
    {
        char ack = SerialBT.read(); // Lire un caractère depuis le buffer
        if (ack == 'A')
        {
            ack_received = true; // L'ACK est reçu
            last_ack = millis();
        }
    }

    // Si un ACK n'est pas reçu depuis plus d'une seconde, on envoie à nouveau les données
    if (millis() - last_ack > 1000)
    {
        ack_received = true;
    }
}

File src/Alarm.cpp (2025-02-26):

//
// Created by Antoine on 03/02/2025.
//

#include "Alarm.h"

Alarm::Alarm(const int pinBuzzer, const int pinLED, const double maxAngle, const double maxTime,
             const double angleAttenuation,
             const double timeAttenuation)
    : pinLED(pinLED), pinBuzzer(pinBuzzer), alarmState(false), silence(false), initialExceedTime(0),
      blinkState(false), lastBlinkChange(0), maxAngle(maxAngle), maxTime(maxTime),
      angleAttenuation(angleAttenuation), timeAttenuation(timeAttenuation)
{
}

void Alarm::init() const
{
    pinMode(pinLED, OUTPUT); // Configure le pin de la LED en sortie
    // pinMode(pinBuzzer, OUTPUT); // Configure le pin du buzzer en sortie

    // Buzzer test
    tone(pinBuzzer, 500);
    delay(50);
    noTone(pinBuzzer);

    // Initialise la LED état bas (éteinte)
    digitalWrite(pinLED, LOW);
}

boolean Alarm::update(const float (&ypr_diff)[3], const double speed)
{
    // Récupère les limites en fonction de la vitesse
    const std::pair<double, double> limits = getLimits(speed);
    const double limitAngle = limits.first;
    const double limitTime = limits.second;
    // Serial.print("Limit angle: "); Serial.print(limitAngle); Serial.print(" Limit time: "); Serial.println(limitTime);

    // Récupère les différences d'angles
    const double diffYaw = ypr_diff[0];
    // REMARQUE : Les angles de tangage et de roulis ne sont pas utilisés pour le moment
    // double diffPitch = ypr_diff[1];
    // double diffRoll = ypr_diff[2];

    // On vérifie si l'angle actuel dépasse la limite
    if (abs(diffYaw) > limitAngle)
    {
        // Si le temps de dépassement est nul (l'angle n'était pas dépassé au temps t-1)
        if (initialExceedTime == 0)
        {
            // On enregistre le temps actuel comme temps initial de dépassement
            initialExceedTime = millis();
        }
        // Si le temps de dépassement est supérieur au temps limite
        if (millis() - initialExceedTime > limitTime * 1000)
        {
            // On déclenche l'alarme
            alarmState = true;
        }
    }
    else
    {
        // Si l'angle n'est plus dépassé, on réinitialise le temps de dépassement
        initialExceedTime = 0;
        // On arrête l'alarme
        alarmState = false;
    }

    // Si l'alarme est déclenchée, on la démarre
    if (alarmState)
    {
        start();
        return true;
    }
    // Sinon, on l'arrête
    else
    {
        stop();
        return false;
    }
}

std::pair<double, double> Alarm::getLimits(const double v_kmh) const
{
    // Calcul des limites d'angle et de temps en fonction de la vitesse : fonction exponentielle décroissante
    double limitAngle = (maxAngle * std::exp(-(angleAttenuation * v_kmh)));
    double limitTime = (maxTime * std::exp((-timeAttenuation * v_kmh)));

    // Retourne les limites
    return std::make_pair(limitAngle, limitTime);
}

void Alarm::start()
{
    Serial.println("Alarm started");
    // Si l'alarme n'est pas en mode silence
    if (!silence)
    {
        // Active le buzzer
        tone(pinBuzzer, 500);
    }

    // Clignotement de la LED toutes les 500ms
    if (lastBlinkChange == 0 || millis() - lastBlinkChange > 500)
    {
        blinkState = !blinkState;
        lastBlinkChange = millis();
    }
    if (blinkState)
    {
        digitalWrite(pinLED, HIGH);
    }
    else
    {
        digitalWrite(pinLED, LOW);
    }
}

void Alarm::stop() const
{
    // On coupe le buzzer et on éteint la LED
    digitalWrite(pinLED, LOW);
    noTone(pinBuzzer);
}

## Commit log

2025-01-21 Répartition de la logique dans différentes fonctions pour un code plus propre et compréhensible. Ajout de commentaires pour plus de clarité
2025-01-22 Ajout du fonctionnement de la LED. La LED clignote quand l'alarme est allumée
2025-01-23 Piece 3D velo
    [case master v5 v5.f3z]
2025-01-27 Ajout de scripts simples pour tester les capteurs et les bibliothèques
2025-01-28 Creation d'une classe Tachymeter pour facilement utiliser les mesures de vitesse
2025-01-29 Implémentation du Tachymètre dans les codes de main et slave. Utilisation de la nouvelle bibliothèque de contrôle du MPU
2025-01-29 Création d'une classe pour gerer le MPU. La classe s'occupe de l'initialisation du calibrage et, si nécessaire du traitement des données. Il reste à l'implémenter dans main et slave
2025-01-30 Integration de la nouvelle classe de contrôle du MPU dans slave et main
2025-01-31 Update main.cpp
    Addition calcule seuils + détection de dépassement
2025-02-04 Ajout du data logging vers la carte SD
2025-02-19 Fonctionnement avec les nouveaux capteurs ICM20948
2025-02-24 Fichier pour tester des nouvelles bibliothèques qui ne seront au final pas utilisées
2025-02-25 Ajout de l'état de l'alarme au logging
2025-02-25 Amélioration des commentaires dans le fichiers main. Modification de noms de fonctions/variables pour respecter les conventions de nommage. Suppression de code non utilisé.
2025-02-26 Commentaires de la classe MPU (MPU.h + MPU.cpp) Modifications du filtre de Kalman pour prendre en compte la discontinuité de l'angle (passage de 0° <=> 360°)
2025-02-26 Commentaires de la classe Alarm
2025-02-26 Commentaires de la classe Tachymeter
2025-02-27 Ajout des fichiers .fzz des schémas des cartes électroniques sur Fritzing
    [master_casque_velo.fzz, slave_casque_velo.fzz]
2025-02-27 Ajout de scripts de tests des capteurs individuels que j'avais oublié de commit
2025-02-27 Utilisation de fonctions trigo dans le filtre de kalman pour une meilleure précision
2025-02-28 Ajout des plots et de acquisitions test sur le git
    [acq4.csv, acq5.csv, sensor_test1.csv]
2025-02-28 Ajout d'un document de description des données
2025-03-10 Correction d'un bug qui faisait que le tachymetre plantait le programme
    [main.cpp, test_sd.cpp, test_tachymeter.cpp]
2025-03-12 Ajout des fichiers pythons pour tracer les plots
2025-03-12 Mis à jour d'une piece 3D du casque parce qu'elle était trop courte
    [casque_2.stl]
